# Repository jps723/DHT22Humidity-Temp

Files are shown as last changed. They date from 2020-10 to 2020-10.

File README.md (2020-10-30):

# DHT22 Humidity/Temp Module Build Notes 3/3/20

This project is in partnership with [Bantam Tools](https://www.bantamtools.com)

**Design Notes:**

This module features the [DHT22 humidity/temperature sensor](https://www.sparkfun.com/datasheets/Sensors/Temperature/DHT22.pdf), also referred to as the AM2302. The pinout is as follows:


On the module, the DHT22 is intended to rest perpendicular to the board.  There is a 4.7k pull-up resistor on the data line, a .1uF filtering capacitor on the VCC line, and a power indicating LED via 1k resistor. The module uses 90 degree male headers allowing for easy breadboarding.  

# Build Process
It’s easiest to solder in this order:
```
1. SMD components
2. Male headers
3. LED
4. DHT22 (bend legs before soldering)
```
**Mill Time**
	Bits: 1/32” & 1/64”: < 3mins
	Or
	1/64” Alone: 8mins

**Test**
```
1. Install the Adafruit DHT Sensor library
2. Examples > DHT Sensor Library > DHTtester
3. Connect 5v to pin1 on the module, connect D2 (Default in example code) to pin2 on the module, and GND to pin3
4. DHT22 is the default type set in the example sketch.  Change this in the code if using a different DHTxx sensor.   
5. Upload code
6.  Open Serial Monitor
```

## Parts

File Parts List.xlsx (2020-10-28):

Part | Quantity | Notes
DHT22 Sensor (AM2302) | 1 | Can be replaced by DHT11
Resistors
4.7k | 1 | 0805 SMD
1k | 1 | 0805 SMD
Ceramic Capacitors
.1uF | 1 | 0805 SMD
LED | 1 | 5mm
Male Headers | 1 | 1x3 90 degree angle

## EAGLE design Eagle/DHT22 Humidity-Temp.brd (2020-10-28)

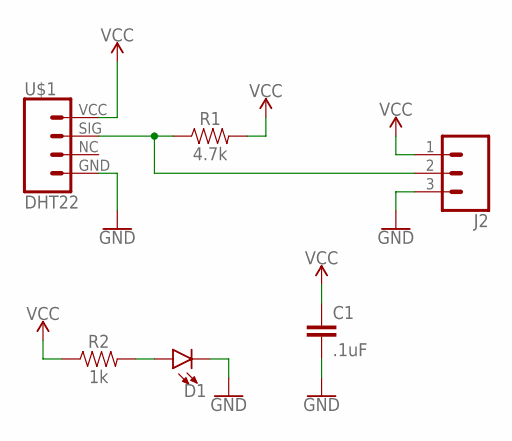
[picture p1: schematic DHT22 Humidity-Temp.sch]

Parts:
C1: .1uF; 0805
D1: LED-3MM-NO_SILK; LED_3MM-NS
J2: CONN_03LONGPADS; 1X03_LONGPADS
R1: 4.7k; 0805
R2: 1k; 0805
U$1: DHT22

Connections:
GND: C1.2, D1.K (C), J2.3, U$1.GND (1)
unnamed: D1.A, R2.2
SIGNAL: J2.2, R1.1, U$1.SIG (3)
VCC: C1.1, J2.1, R1.2, R2.1, U$1.VCC (4)

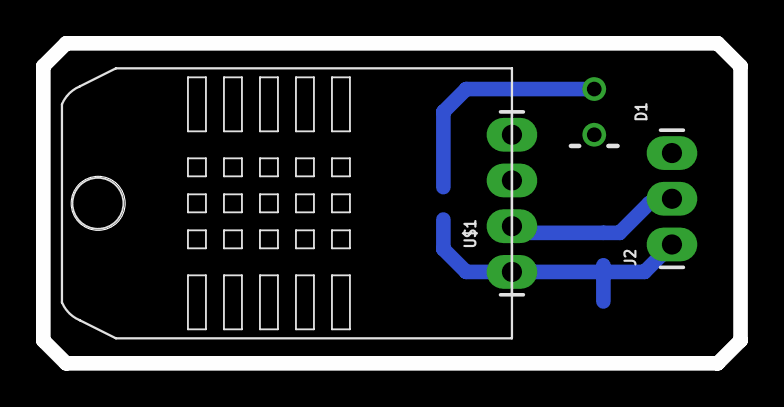
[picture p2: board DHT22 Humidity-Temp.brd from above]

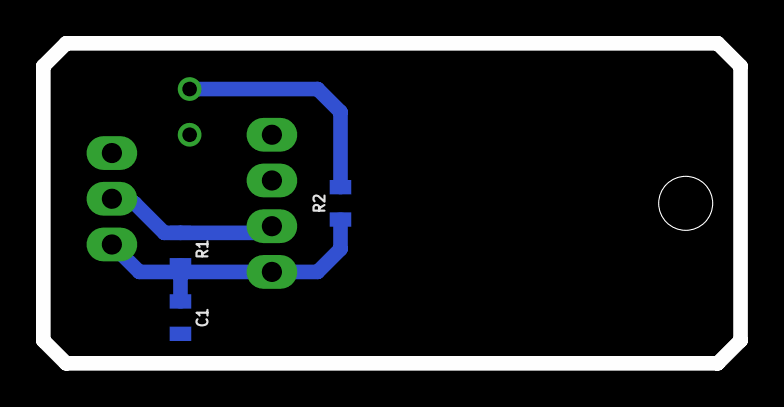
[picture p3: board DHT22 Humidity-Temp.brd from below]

Board: 2 copper layers, 38.7 x 17.8 mm, 6 parts (3 on the bottom side), 4 nets.

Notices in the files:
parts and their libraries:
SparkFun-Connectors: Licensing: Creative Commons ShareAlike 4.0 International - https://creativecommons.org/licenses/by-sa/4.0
